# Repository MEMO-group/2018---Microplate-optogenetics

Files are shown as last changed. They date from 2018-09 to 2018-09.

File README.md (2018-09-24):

# Microplate illuminator
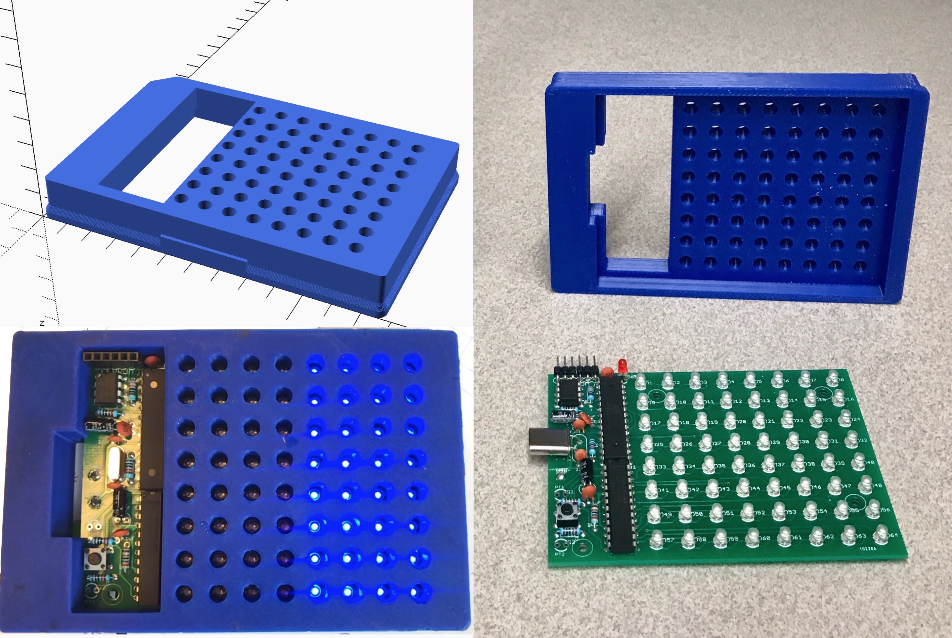
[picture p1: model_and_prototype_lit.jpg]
Composite picture

CAD model and 3D-printed prototype of the microplate illuminator. The assembled circuit board is affixed to the printed housing using mouldable glue or screws,and programmed via the serial interface header and the Arduino software.  During operation a microplate is placed on top of the device, which is then incubated on a microplate shaker; the microplate should have opaque wals and a transparant lid, the incubator should be placed in a darkened room without reflective surfaces or covered with e.g. a styrofoam cooler lined with black felt.

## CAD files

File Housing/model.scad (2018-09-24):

// model resolution
$fs=0.5;
$fa=5;

// ANSI standard microplate (dimensions in mm)
base_l = 127.76;
base_w = 85.48;
corner_r = 3.18;
flange_h = 2.41;
flange_w = 1.27;
plate_h = 14.35;
chamfer = 7; // optional, size not specified
interruption_x0 = 47.8; // distance between edges of interruption and edges of plate
interruption_h = 6.85;

n_rows = 8;
n_cols = 12;

well_x0 = 14.38; // distance between the left outside edge of the plate and the center of the first column of wells
well_y0 = 11.24; // distance between the top outside edge of the plate and the center of the first row of wells
well_dx = 9; // distance between well centers
well_dy = 9;


led_hole_diam = 4.02 + 1; // 1 mm clearance
led_h = 4.1 + 2; // 2 mm soldering tolerance
led_hole_depth = led_h + 3;
pcb_l = 100;
pcb_w = 75;
pcb_tol = 2; // allow for 2 mm space on both sides
height = 16; // make device slightly higher than normal microplate

// optional mounting holes:
mounting_holes = [[10,5],[36,64],[90,64],[90,19]];
// M2 standard bolts (with 1 mm tolerance)
screw_diam = 2 + 1;
screw_head_diam = 3.8 + 1;
screw_head_height = 3 + 1;

// positioning help: topright led center is 6 mm from each pcb edge
pcb_x = (well_x0 + well_dx*(n_cols-1)) - (pcb_l - 6);
pcb_y = (base_w - well_y0) - (pcb_w - 6);

// space for PCB components, relative to pcb
pocket_xmin = 1; // bottom left
pocket_ymin = 1;
pocket_xmax = 27;
pocket_ymax = 74;
pocket_h = 10;


// module and function definitions
module rounded_rect(dimensions, r, topleft_chamfer=0){
    w = dimensions[0];
    l = dimensions[1];
    hull(){
        // draw 4 circles in the corners
        translate([r, r])
            circle(r=r);
        if(topleft_chamfer>0){
            translate([r, w-r-topleft_chamfer])
                circle(r=r);
            translate([r+topleft_chamfer, w-r])
                circle(r=r);
        }else{
            translate([r, w-r])
                circle(r=r);
        }
        translate([l-r, r])
            circle(r=r);
        translate([l-r, w-r])
            circle(r=r);
    }
}
translate([0,base_w,height]) rotate([180,0,0])
difference(){
  union(){
    flange_h = 2.41*2;
    linear_extrude(flange_h/2)
      rounded_rect([base_w,base_l],corner_r);
    for(i = [0:10]){
      translate([flange_w*i/10, flange_w*i/10,0])
      linear_extrude(flange_h/2*(1+(i+1)/10))
        rounded_rect([base_w-2*i/10*flange_w,base_l-2*i/10*flange_w],corner_r-i/10*flange_w);
    }

    linear_extrude(height)
      translate([flange_w,flange_w])
        rounded_rect([base_w-flange_w*2,base_l-flange_w*2], corner_r-flange_w, chamfer);
        // alternatively, without the top-left corner cut off:
        // rounded_rect([base_w-flange_w*2,base_l-flange_w*2], corner_r-flange_w);
    // optional: include interuptions from the ANSI standard:
    linear_extrude(interruption_h)
      translate([interruption_x0,0])
        square([base_l-interruption_x0*2,flange_w]);
    linear_extrude(interruption_h)
      translate([interruption_x0,base_w-flange_w])
        square([base_l-interruption_x0*2,flange_w]);
  }
  
  // LED holes:
  for(y = [0:n_rows-1]){
    for(x = [4:n_cols-1]){
      translate([well_x0+x*well_dx, base_w-well_y0-y*well_dy, height/2]) cylinder(height+2,d=led_hole_diam,center=true);
    }
  }

  // pocket for PCB:
  translate([pcb_x-pcb_tol,pcb_y-pcb_tol,-1])
    linear_extrude(height-led_hole_depth+1)
      square([pcb_l+2*pcb_tol,pcb_w+2*pcb_tol]);

  // pocket for electronic components:
  translate([pcb_x,pcb_y,-1])
    linear_extrude(height-led_hole_depth+pocket_h+1)
      polygon([[pocket_xmin,pocket_ymin],
               [pocket_xmin,pocket_ymax],
               [pocket_xmax,pocket_ymax],
               [pocket_xmax,pocket_ymin]]);

  // (optional: extra space (5mm) for the longer crystal used in the prototype)
  //translate([pcb_x-5,pcb_y+pcb_w/3,-1])
  //  linear_extrude(height-led_hole_depth+pocket_h+1)
  //    square([10,pcb_w/3+2*pcb_tol]);

  // (optional: countersunk pcb mounting holes)
  for(i = [0:len(mounting_holes)-1]){
    translate([pcb_x + mounting_holes[i][0], pcb_y + mounting_holes[i][1], height/2])
      cylinder(height+2, d=screw_diam, center=true);
    translate([pcb_x + mounting_holes[i][0], pcb_y + mounting_holes[i][1], (screw_head_height+1)/2 + (height-screw_head_height)])
      cylinder(screw_head_height+1, d=screw_head_diam, center=true);
  }
}

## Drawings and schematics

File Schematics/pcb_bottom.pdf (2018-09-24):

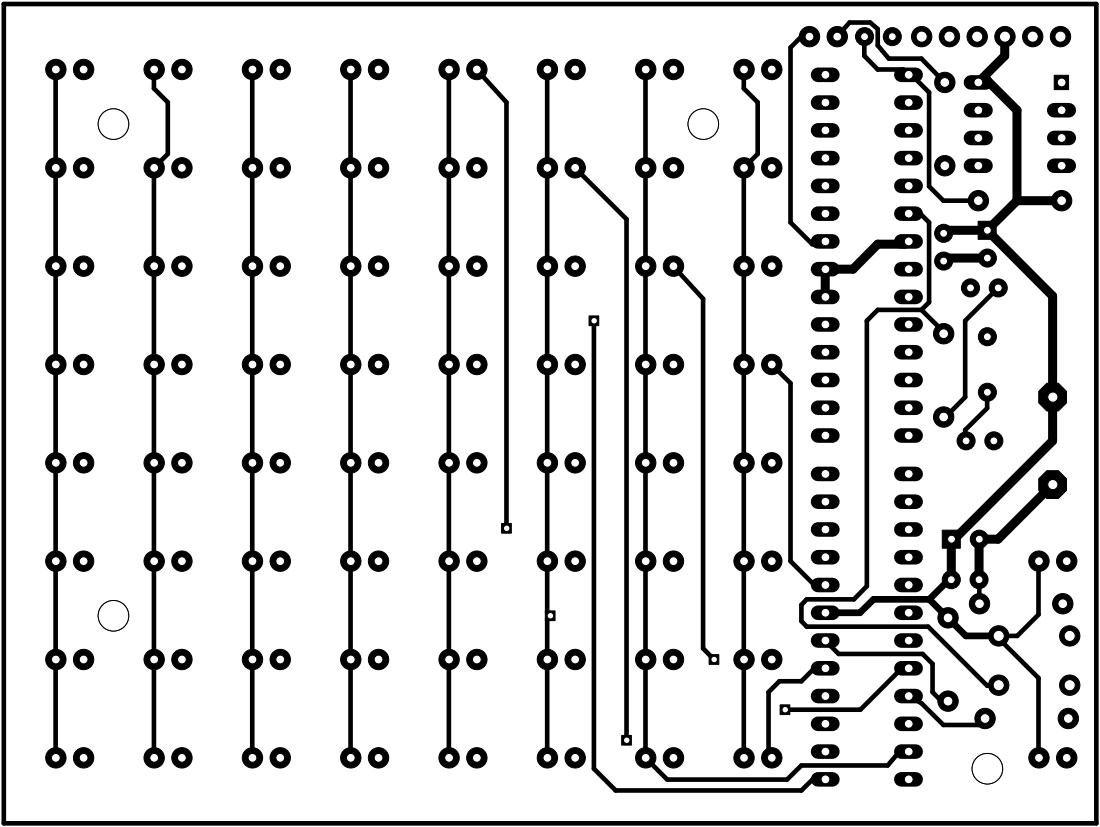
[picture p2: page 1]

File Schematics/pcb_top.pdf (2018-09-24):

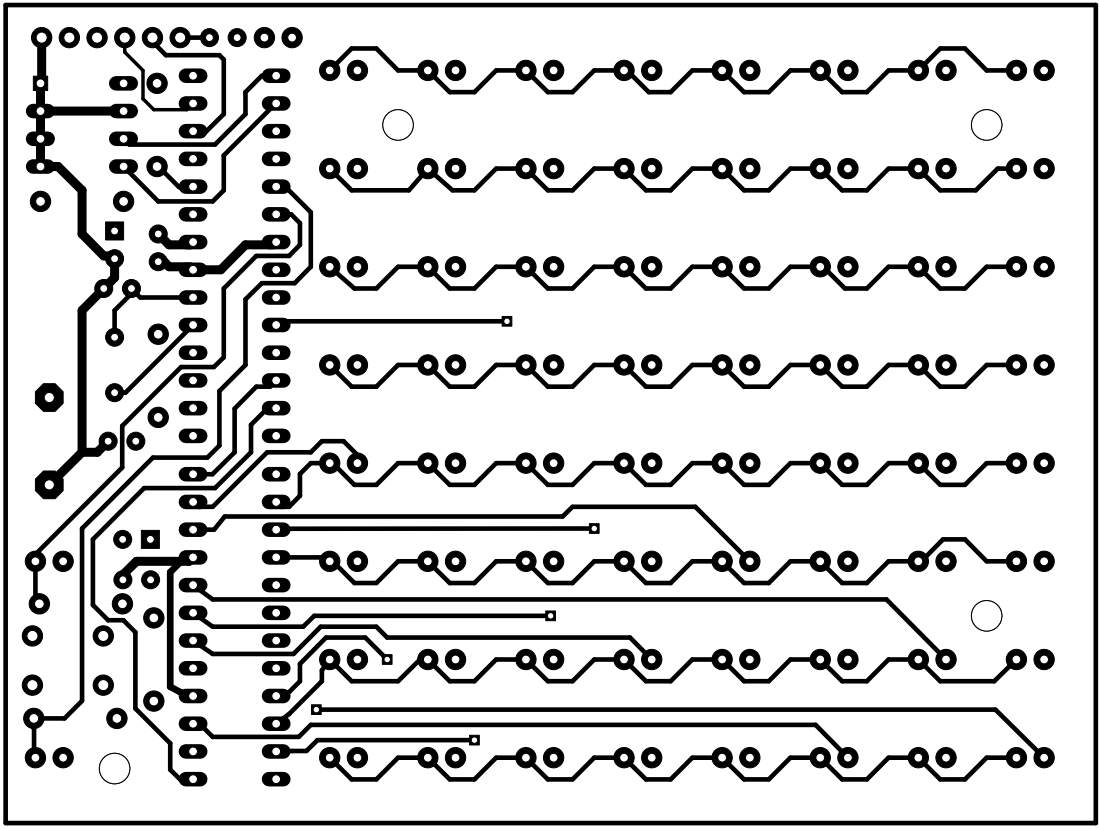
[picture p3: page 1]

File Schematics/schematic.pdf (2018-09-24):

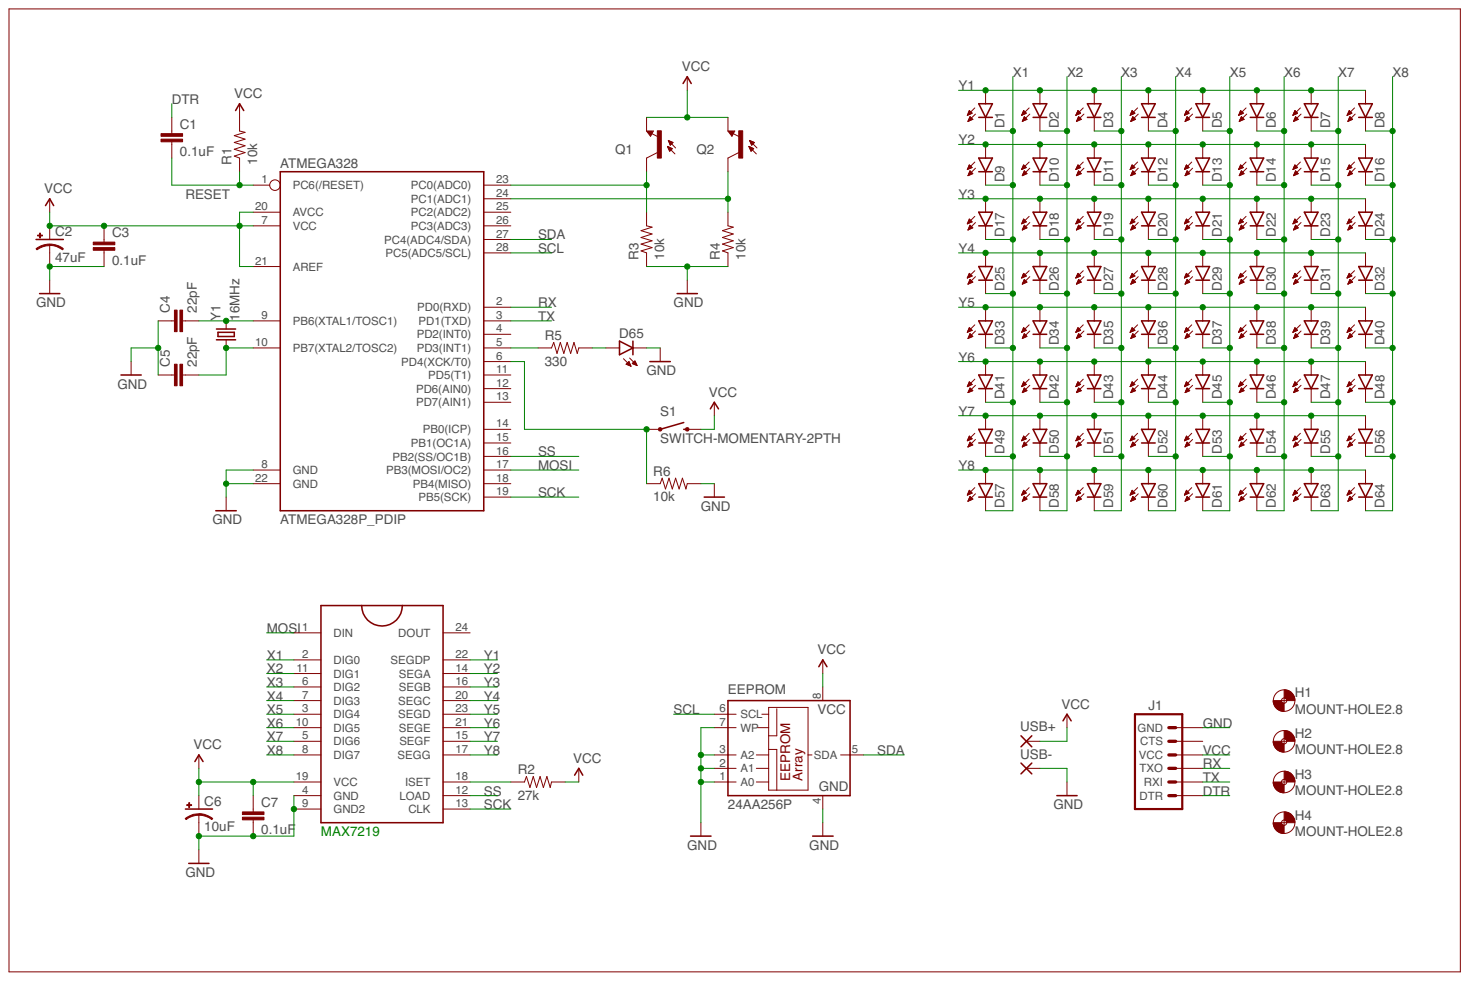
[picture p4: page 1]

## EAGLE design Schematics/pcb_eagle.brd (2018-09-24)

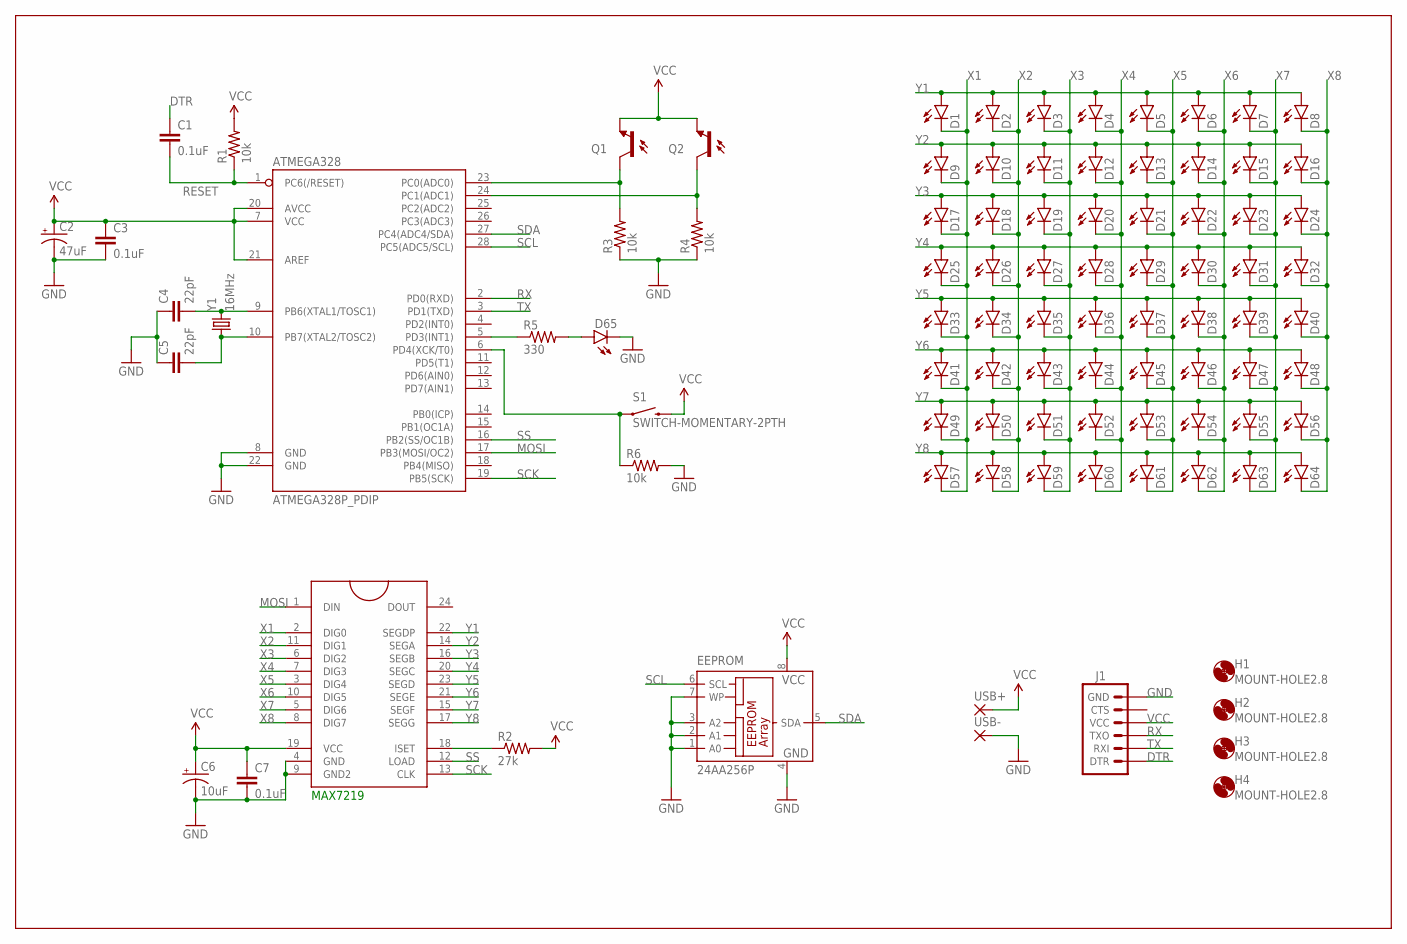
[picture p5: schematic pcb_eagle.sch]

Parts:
ATMEGA328: ATMEGA328P_PDIP; DIL28-3
C1, C3, C7: 0.1uF; CAP-PTH-SMALL
C2: 47uF; CPOL-RADIAL-10UF-25V
C4, C5: 22pF; CAP-PTH-SMALL
C6: 10uF; CPOL-RADIAL-10UF-25V
D1, D2, D3, D4, D5, D6, D7, D8, D9, D10, D11, D12, D13, D14, D15, D16, D17, D18, D19, D20, D21, D22, D23, D24, D25, D26, D27, D28, D29, D30, D31, D32, D33, D34, D35, D36, D37, D38, D39, D40, D41, D42, D43, D44, D45, D46, D47, D48, D49, D50, D51, D52, D53, D54, D55, D56, D57, D58, D59, D60, D61, D62, D63, D64, D65: LED3MM
EEPROM: 24AA256P; DIL8
H1, H2, H3, H4: MOUNT-HOLE2.8; 2,8
J1: ARDUINO_SERIAL_PROGRAMPTH; 1X06
MAX72191: MAX7219DIP; DIL24
Q1, Q2: PHOTOTRANSISTORT1; LED3MM
R1, R3, R4, R6: 10k; AXIAL-0.3
R2: 27k; AXIAL-0.3
R5: 330; AXIAL-0.3
S1: SWITCH-MOMENTARY-2PTH; TACTILE-PTH
USB+: 2,54/0,9
USB-: 2,54/0,9
Y1: 16MHz; HC49US

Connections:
DTR: C1.1, J1.1 (DTR)
GND: ATMEGA328.8 (GND), ATMEGA328.22 (GND), C2.2 (-), C3.2, C4.1, C5.1, C6.2 (-), C7.2, D65.K (C), EEPROM.1 (A0), EEPROM.2 (A1), EEPROM.3 (A2), EEPROM.4 (GND), EEPROM.7 (WP), J1.6 (GND), MAX72191.4 (GND), MAX72191.9 (GND2), R3.P$1 (1), R4.P$1 (1), R6.P$2 (2), USB-.1
MOSI: ATMEGA328.17 (PB3(MOSI/OC2)), MAX72191.1 (DIN)
unnamed: ATMEGA328.9 (PB6(XTAL1/TOSC1)), C4.2, Y1.2
unnamed: ATMEGA328.10 (PB7(XTAL2/TOSC2)), C5.2, Y1.1
unnamed: MAX72191.18 (ISET), R2.P$1 (1)
unnamed: ATMEGA328.24 (PC1(ADC1)), Q2.C, R4.P$2 (2)
unnamed: ATMEGA328.23 (PC0(ADC0)), Q1.C, R3.P$2 (2)
unnamed: ATMEGA328.5 (PD3(INT1)), R5.P$1 (1)
unnamed: D65.A, R5.P$2 (2)
unnamed: ATMEGA328.6 (PD4(XCK/T0)), R6.P$1 (1), S1.1
RESET: ATMEGA328.1 (PC6(/RESET)), C1.2, R1.P$1 (1)
RX: ATMEGA328.2 (PD0(RXD)), J1.3 (TXO)
SCK: ATMEGA328.19 (PB5(SCK)), MAX72191.13 (CLK)
SCL: ATMEGA328.28 (PC5(ADC5/SCL)), EEPROM.6 (SCL)
SDA: ATMEGA328.27 (PC4(ADC4/SDA)), EEPROM.5 (SDA)
SS: ATMEGA328.16 (PB2(SS/OC1B)), MAX72191.12 (LOAD)
TX: ATMEGA328.3 (PD1(TXD)), J1.2 (RXI)
VCC: ATMEGA328.7 (VCC), ATMEGA328.20 (AVCC), ATMEGA328.21 (AREF), C2.1 (+), C3.1, C6.1 (+), C7.1, EEPROM.8 (VCC), J1.4 (VCC), MAX72191.19 (VCC), Q1.E, Q2.E, R1.P$2 (2), R2.P$2 (2), S1.3 (2), USB+.1
X1: D1.K (C), D9.K (C), D17.K (C), D25.K (C), D33.K (C), D41.K (C), D49.K (C), D57.K (C), MAX72191.2 (DIG0)
X2: D2.K (C), D10.K (C), D18.K (C), D26.K (C), D34.K (C), D42.K (C), D50.K (C), D58.K (C), MAX72191.11 (DIG1)
X3: D3.K (C), D11.K (C), D19.K (C), D27.K (C), D35.K (C), D43.K (C), D51.K (C), D59.K (C), MAX72191.6 (DIG2)
X4: D4.K (C), D12.K (C), D20.K (C), D28.K (C), D36.K (C), D44.K (C), D52.K (C), D60.K (C), MAX72191.7 (DIG3)
X5: D5.K (C), D13.K (C), D21.K (C), D29.K (C), D37.K (C), D45.K (C), D53.K (C), D61.K (C), MAX72191.3 (DIG4)
X6: D6.K (C), D14.K (C), D22.K (C), D30.K (C), D38.K (C), D46.K (C), D54.K (C), D62.K (C), MAX72191.10 (DIG5)
X7: D7.K (C), D15.K (C), D23.K (C), D31.K (C), D39.K (C), D47.K (C), D55.K (C), D63.K (C), MAX72191.5 (DIG6)
X8: D8.K (C), D16.K (C), D24.K (C), D32.K (C), D40.K (C), D48.K (C), D56.K (C), D64.K (C), MAX72191.8 (DIG7)
Y1: D1.A, D2.A, D3.A, D4.A, D5.A, D6.A, D7.A, D8.A, MAX72191.22 (SEGDP)
Y2: D9.A, D10.A, D11.A, D12.A, D13.A, D14.A, D15.A, D16.A, MAX72191.14 (SEGA)
Y3: D17.A, D18.A, D19.A, D20.A, D21.A, D22.A, D23.A, D24.A, MAX72191.16 (SEGB)
Y4: D25.A, D26.A, D27.A, D28.A, D29.A, D30.A, D31.A, D32.A, MAX72191.20 (SEGC)
Y5: D33.A, D34.A, D35.A, D36.A, D37.A, D38.A, D39.A, D40.A, MAX72191.23 (SEGD)
Y6: D41.A, D42.A, D43.A, D44.A, D45.A, D46.A, D47.A, D48.A, MAX72191.21 (SEGE)
Y7: D49.A, D50.A, D51.A, D52.A, D53.A, D54.A, D55.A, D56.A, MAX72191.15 (SEGF)
Y8: D57.A, D58.A, D59.A, D60.A, D61.A, D62.A, D63.A, D64.A, MAX72191.17 (SEGG)

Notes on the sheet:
MAX7219

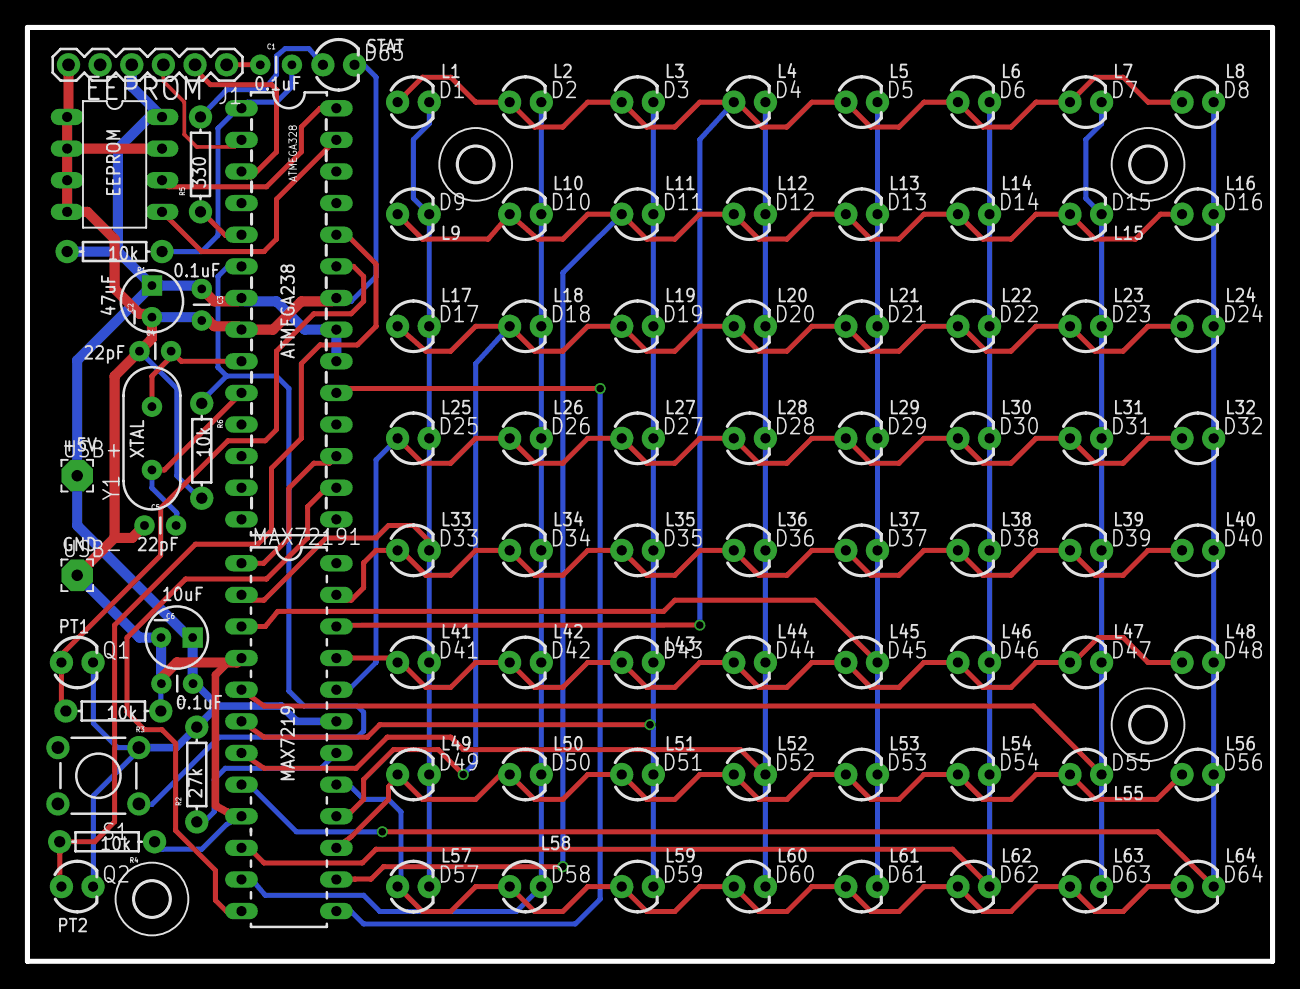
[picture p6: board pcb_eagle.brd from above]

Board: 2 copper layers, 100.0 x 75.0 mm, 92 parts (0 on the bottom side), 35 nets.

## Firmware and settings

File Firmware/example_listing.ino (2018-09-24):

#include <SPI.h>
#include <Wire.h>

//#define DEBUG

// Pin definitions
#define STAT 3 // status LED
#define BTN 4  // pushbutton

// SPI pins (only these support hardware SPI!)
#define SS  10  // Slave Select
#define MOSI 11 // Master Out Slave In
#define SCK 13  // Serial ClocK

// I2C pins are initialised by Wire.h
// SDA: analog 4
// SCL: analog 5

// Max7219 registers
#define REG_NOOP           0x00
//REG_COLUMN:       0x01 - 0x08
#define REG_DECODEMODE     0x09
#define REG_INTENSITY      0x0a
#define REG_SCANLIMIT      0x0b
#define REG_SHUTDOWN       0x0c
#define REG_DISPLAYTEST    0x0f

// EEPROM address
#define DISK               0x50
#define INS_LEN            16

// Mtp led columns are wired to the DIG pins via a common cathode (-)
// Mtp led rows are wired to the SEG pins via a common anode (+)

// Lighting instruction data structure (directly accessible as byte array)
typedef struct __attribute__((packed)) ins{
    // 2 bytes: jump address BUT: 4 least significant bits store the brightness
    // 2 bytes: number of repeats for the jump
    // 4 bytes: duration in ms (unsigned long)
    // 8 bytes: LED matrix (column by column)
    uint16_t jump;
    uint16_t repeats;
    uint32_t duration;
    byte leds[8];
  } INS; // exactly 16 bytes, this must be enforced
// Example: INS instruction = {0 + 0xB, 2*1000, 10, {0xFF,0xFF,0xFF,0xFF,0xFF,0xFF,0xFF,0xFF}};
// Pointer to raw byte array can be passed like this: (byte *) &instruction

// Debugging functions:
#ifdef DEBUG
void print_instruction(struct ins *i)
{
  char buf[128];
  sprintf(buf, "intensity: %2d; duration: %lu ms; jump to %u x %u times; LEDs: %02x:%02x:%02x:%02x:%02x:%02x:%02x:%02x",
    (i->jump & 0x0F), i->duration, (i->jump & 0xFFF0)/INS_LEN, i->repeats,
    i->leds[0], i->leds[1], i->leds[2], i->leds[3], i->leds[4], i->leds[5], i->leds[6], i->leds[7]);
  Serial.println(buf);
}
int get_free_memory()
{
  // Credit: https://learn.adafruit.com/memories-of-an-arduino/measuring-free-memory
  extern int __heap_start, *__brkval;
  int v;
  return (int) &v - (__brkval == 0 ? (int) &__heap_start : (int) __brkval);
}
#endif

// MAX7219 LED driver functions:
void send_cmd(byte address, byte value){
  // Take the SS pin low to select the chip:
  digitalWrite(SS,LOW);
  // Send in the address and value via SPI:
  SPI.transfer(address);
  SPI.transfer(value);
  // Take the SS pin high to de-select the chip:
  digitalWrite(SS,HIGH);
}
void max7219_init() {
  send_cmd(REG_SCANLIMIT, 0x07);
  send_cmd(REG_DECODEMODE, 0x00);  // Using an led matrix (not digits)
  send_cmd(REG_SHUTDOWN, 0x01);    // Not in shutdown mode
  send_cmd(REG_DISPLAYTEST, 0x00); // No display test
  for (int c=1; c<=8; c++) {    // Turn all LED off
    send_cmd(c,0);
  }
  send_cmd(REG_INTENSITY, 0x0f & 0x0f); // 0x0f is used as a mask since you can only set 16 levels
}
void clear_display(){
  for (uint8_t c=1; c<=8; c++){ send_cmd(c, 0);}
}

// 24LC256 EEPROM functions:
void write_bytes(uint16_t address, byte *source)
{
  // This does NOT take into account page boundaries
  //  (pages are 64 bytes wide)
  Wire.beginTransmission(DISK);
  Wire.write((byte)(address >> 8));   // MSB
  Wire.write((byte)(address & 0xFF)); // LSB
  for (uint8_t i = 0; i < INS_LEN; i++){
    Wire.write((byte) source[i]);
  }
  Wire.endTransmission();
  delay(6); // Give EEPROM IC time to write
}
void read_bytes(uint16_t address, byte *destination)
{
  // Read instruction from address as a byte array
  Wire.beginTransmission(DISK);
  Wire.write((byte)(address >> 8));   // MSB
  Wire.write((byte)(address & 0xF0)); // LSB, discarding 4 least significant bits
  Wire.endTransmission();
  Wire.requestFrom(DISK,INS_LEN);
  uint8_t i = 0;
  while(Wire.available()) destination[i++] = Wire.read(); // Should not overflow (destination length == INS_LEN)
}

// Lighting program interpreter:
void parse_protocol(uint16_t address, uint16_t endAddress)
{
  INS *instruction;
  instruction = (ins *) malloc(INS_LEN); // Remember to free() later
  for(;;){
    read_bytes(address, (byte *) instruction);
#ifdef DEBUG
    Serial.print("Program line "); Serial.println(address/INS_LEN);
    print_instruction(instruction);
    Serial.print("Free memory: "); Serial.println(get_free_memory());
#endif
    // Light LEDS
    send_cmd(REG_INTENSITY, (byte) instruction->jump & 0x0F); // brightness is encoded the pointer to the next instruction
    for(uint8_t c=0; c<8; c++){ send_cmd(c+1, instruction->leds[c]); }

    // Wait
    delay(instruction->duration);

    // Magic number to indicate final instruction
    if(instruction->jump == 0xFFFF){break;}

    // Iteration with recursion for the jumps
    if(address == endAddress){break;}
    for(uint16_t i=1; i<=instruction->repeats; i++){
#ifdef DEBUG
      Serial.print("Executing jump ");Serial.print(i);Serial.print(" of ");Serial.print(instruction->repeats);
      Serial.print(" to program line ");Serial.println((instruction->jump & 0xF0)/INS_LEN );
#endif
      parse_protocol(instruction->jump & 0xFFF0, address);
    }
    address += INS_LEN;
  }
  free(instruction); // Otherwise we get a memory leak
}

// Overloaded function definition to allow for optional arguments
void parse_protocol()
{
  parse_protocol(0x0000, 0xFFFF);
}

void setup() {

#ifdef DEBUG
    // Serial console
    delay(1000); // Give time for serial monitor to come up
    Serial.begin(9600);
    Serial.print("Initialised...\n");
    Serial.print("Free memory: "); Serial.println(get_free_memory());
#endif
    //  Setup pins
    pinMode(STAT, OUTPUT); // Status LED
    pinMode(BTN, INPUT); // Pushbutton
    pinMode(SS, OUTPUT);
    pinMode(MOSI, OUTPUT);
    pinMode(SCK, OUTPUT);
    //  Initialize SPI parameters
    SPI.begin();
    SPI.setBitOrder(MSBFIRST);  //  Most significant bit is sent first
    SPI.setDataMode(SPI_MODE3); //  Data is latched into device on rising edge
    SPI.setClockDivider(SPI_CLOCK_DIV4); //  Clock is 16MHz/4 = 4Mhz < 10Mhz max device speed
    // Initialize I2C bus (pins hardcoded in library)
    Wire.begin();

    // Initialize Max7219 LED driver chip
    max7219_init();
    clear_display();

    // Define program (harcoded example)
    INS prog[] = {{0 | 0x01, 0U, 3600000UL, { 0x00, 0x00, 0x00, 0x00, 0x00, 0x00, 0x00, 0x00 }}, // -1h
                  {0 | 0x01, 0U, 3600000UL, { 0x00, 0x00, 0x00, 0x00, 0x00, 0x00, 0x00, 0xFF }}, // 0h
                  {0 | 0x01, 0U, 3600000UL, { 0x00, 0x00, 0x00, 0x00, 0x00, 0x00, 0xFF, 0xFF }}, // 1h
                  {0 | 0x01, 0U, 3600000UL, { 0x00, 0x00, 0x00, 0x00, 0x00, 0xFF, 0xFF, 0xFF }}, // 2h
                  {0 | 0x01, 0U, 3600000UL, { 0x00, 0x00, 0x00, 0x00, 0xFF, 0xFF, 0xFF, 0xFF }}, // 3h
                  {0 | 0x01, 0U, 3600000UL, { 0x00, 0x00, 0x00, 0xFF, 0xFF, 0xFF, 0xFF, 0xFF }}, // 4h
                  {0 | 0x01, 0U, 1800000UL, { 0x00, 0x00, 0xFF, 0xFF, 0xFF, 0xFF, 0xFF, 0xFF }}, // 5h
                  {0 | 0x01, 0U,  900000UL, { 0x00, 0xFF, 0xFF, 0xFF, 0xFF, 0xFF, 0xFF, 0xFF }}, // 5h30
                  {0 | 0x01, 0U,  900000UL, { 0xFF, 0xFF, 0xFF, 0xFF, 0xFF, 0xFF, 0xFF, 0xFF }}, // 5h45
                  {0 | 0x01, 0U, 3600000UL, { 0x00, 0x00, 0x00, 0x00, 0x00, 0x00, 0x00, 0x00 }}};// 6h

    for(uint8_t i = 0; i < sizeof(prog)/INS_LEN; i++){
      write_bytes(i*INS_LEN,(byte *) &prog[i]);
    }
#ifdef DEBUG
  Serial.print("Free memory: "); Serial.println(get_free_memory());
#endif
}

void loop() {
  parse_protocol();
}

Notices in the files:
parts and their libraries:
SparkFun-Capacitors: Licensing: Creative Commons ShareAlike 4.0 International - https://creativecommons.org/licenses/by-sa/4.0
